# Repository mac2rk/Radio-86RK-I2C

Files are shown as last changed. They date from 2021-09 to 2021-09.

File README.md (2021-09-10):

# I2C interface for i8080 (and simlilar) computers

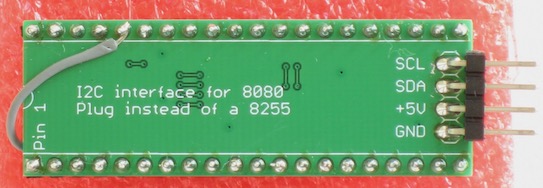
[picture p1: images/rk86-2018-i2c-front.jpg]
Board top


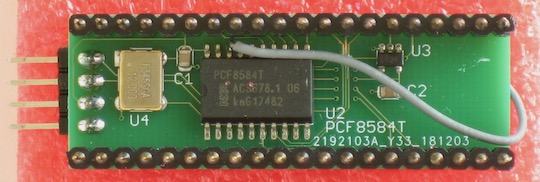
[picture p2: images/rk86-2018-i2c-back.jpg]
Board bottom


(The wire fixes an error in an intial version of the board; in the Eagle and Gerber files available here the error has been fixed.)

## Introduction

This project is an I2C interface for i8080/i8085/Z80-based computers. The interface is bulit around NXP's PCF8584 I2C bus controller. The PCB is size- and pin-compatible with the i8255 Programmable Peripheral Interface and can be plugged into i8255's socket (of course it requires different code to setup and run). A code example is provided.

## Schematic

[Schematic](Eagle/Radio86RK-I2C-schematic.pdf)

The schematic follows the datasheet for the PCF8584. 

## PCB layout 

[PCB layout](Eagle/Radio86RK-I2C-pcb.pdf)

Note that all parts, with the possible exception of the 4-pin I2C header, are on the underside of the PCB.

## Bill of Materials

U1 (8255) in the schematic is just the DIL male socket, not the actual IC.

Depending on PCF8584 programming, the following oscillator (U4) frequencies can be used: 3, 4.43, 6, 8, 12MHz. With a different board, the clock can of course be shared with the CPU or other preriperals.

Name  | Part               | Value   | Package | Quantity
----- | ------------------ | ------- | ------- | --------
U2    | I2C-bus controller | PCF8584T | S020   | 1
U3    | Signle NAND gate | 741G00DBV | SOT23-5 | 1
U4    | Oscillator         | 12MHz   | 5x7mm   | 1
C1,C2 | Capacitor          | 0.1uF   | 0805    | 2
I2C   | 0.1" pin header    |         | 1x4     | 1

## Example code

Intel 8080 assembler - can be compiled with e.g. [asm8080](https://github.com/mac2rk/asm8080). The code assumes that the PCF8584 I/O ports are mapped to memory addresses 0A000h (data port) and 0A001h (control port). 

    ; PCF8584 use example
    ; 
    ; Define PCF8584 ports
    PCF_BASE    EQU     0A000h
    DATA_REG    EQU     0
    CTRL_REG    EQU     1
    PCF_DATA    EQU     PCF_BASE+DATA_REG
    PCF_CTRL    EQU     PCF_BASE+CTRL_REG
    ;
    ; Define PCF8584 status bit masks
    PCF_BBN     EQU     01h             ; bus busy, active low
    PCF_PIN     EQU     80h             ; pending interrupt, active low
    PCF_LRB     EQU     08h             ; last received bit (typically the ACK bit)
    ;
    ; Define slave address
    SLAVE_ADDR  EQU     8
    ; Byte to send to the slave
    DATA_BYTE   EQU     'A'
    ;
                ORG     0
    ; initialize PCF8584
    PCF_INIT:
    ; program own slave address (this is required even if the address is not used)
                MVI     A, 80h          ; serial interface off; next byte will be loaded into register own address register
                STA     PCF_CTRL
                MVI     A, 55h          ; effective own address becomes 0AAh (55h<<1)
                STA     PCF_DATA
    ; program clock and I2C bus speed
                MVI     A, 0A0h         ; next byte will be loaded into the clock control register S2
                STA     PCF_CTRL
                MVI     A, 1Ch          ; system clock is 12 MHz; SCL = 90 kHz
                STA     PCF_DATA
    ; enable serial interface
                MVI     A, 0C1h         ; enable serial interface, set I2C-bus into idle mode
                STA     PCF_CTRL
    ;
    ; now send something to a slave
    PCF_MASTER_TX:
    ; wait for bus availability
                LDA     PCF_CTRL        ; load status byte
                ANI     PCF_BBN         ; is bus available?
                JZ      PCF_MASTER_TX   ; JIF not available
    ; form the slave address with the R/W bit (R=1, W=0) at LSB
                XRA     A               ; Carry = 0
                MVI     A, SLAVE_ADDR   ; load slave address
                RAL                     ; shift address left, set R/W bit to 0 (write)
                STA     PCF_DATA
    ; generate START condition on the I2C bus and clock out the address byte
                MVI     A, 0C5h          
                STA     PCF_CTRL        ; transmit address + R/W bit
    TX10:
    ; wait for the transmission to finish
                LDA     PCF_CTRL        ; load status byte
                MOV     B, A            ; store status byte to check for acknowledgement later
                ANI     PCF_PIN         ; is transmission complete?
                JNZ     TX10            ; keep polling if not complete
                MOV     A, B
    ; check if the slave acknowledged the address
                ANI     PCF_LRB         ; slave acknowledged?
                JNZ     TXSTOP          ; JIF not acknowledged; maybe the slave is busy or not present at that address
    ; slave acknowledged the address, so send the data
                MVI     A, DATA_BYTE    ; byte to be transferred
                STA     PCF_DATA        ; send the data byte to the slave
    TX20:
    ; wait for the transmission to finish
                LDA     PCF_CTRL        ; load status byte
                ANI     PCF_PIN         ; is transmission complete?
                JNZ     TX20            ; keep polling if not complete
    ; here one can check for acknowledgement and send the next byte, etc.
    TXSTOP:
    ; generate STOP condition on the I2C bus
                MVI     A, 0C3h          
                STA     PCF_CTRL        ; generate STOP condition
    ;
                JMP     PCF_MASTER_TX   ; repeat sending sequence

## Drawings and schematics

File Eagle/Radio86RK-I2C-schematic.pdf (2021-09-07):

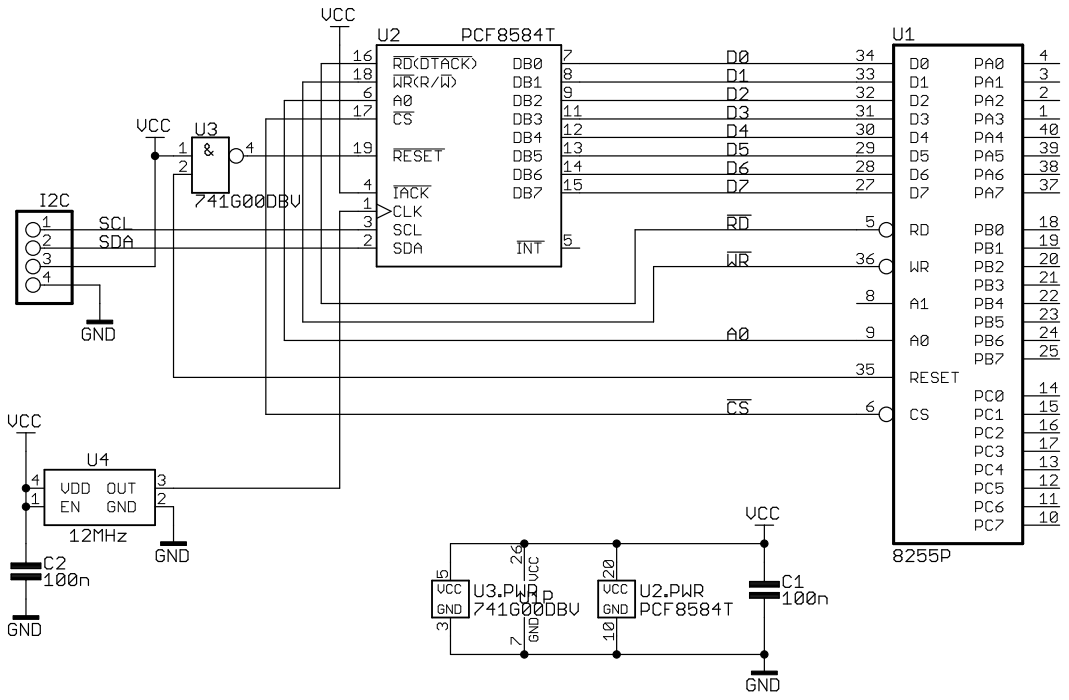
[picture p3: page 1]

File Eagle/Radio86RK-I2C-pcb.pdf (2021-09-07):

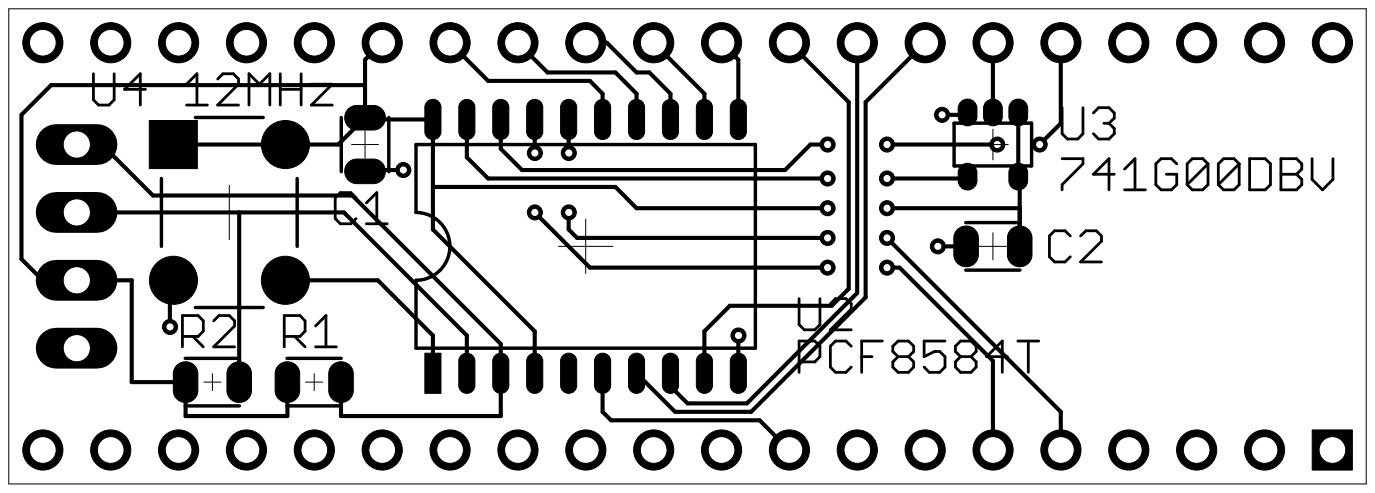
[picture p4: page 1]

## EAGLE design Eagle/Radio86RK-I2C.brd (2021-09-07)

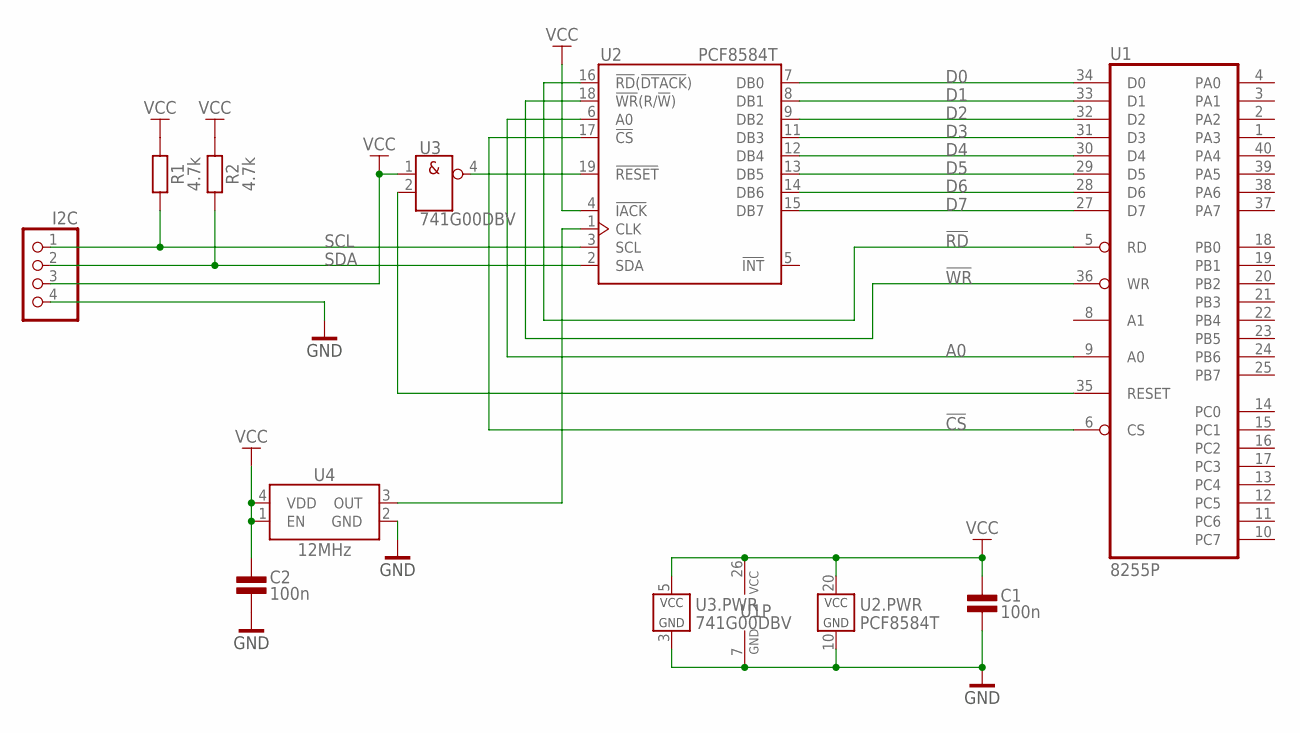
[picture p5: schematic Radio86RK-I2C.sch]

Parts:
C1, C2: 100n; 0805@1
I2C: PINHD-1X4; 1X04
R1, R2: 4.7k; 0805
U1: 8255P; DIP40W
U2: PCF8584T; SO20W
U3: 741G00DBV; SOT23-5
U4: 12MHz; XT_5X7

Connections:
!CS: U1.6 (CS), U2.17 (!CS)
!RD: U1.5 (RD), U2.16 (!RD!(!DTACK!))
!WR: U1.36 (WR), U2.18 (!WR!(R/!W!))
A0: U1.9 (A0), U2.6 (A0)
D0: U1.34 (D0), U2.7 (DB0)
D1: U1.33 (D1), U2.8 (DB1)
D2: U1.32 (D2), U2.9 (DB2)
D3: U1.31 (D3), U2.11 (DB3)
D4: U1.30 (D4), U2.12 (DB4)
D5: U1.29 (D5), U2.13 (DB5)
D6: U1.28 (D6), U2.14 (DB6)
D7: U1.27 (D7), U2.15 (DB7)
GND: C1.1, C2.1, I2C.4, U1.7 (GND), U2.10 (GND), U3.3 (GND), U4.2 (GND)
unnamed: U2.19 (!RESET), U3.4 (Y)
unnamed: U2.1 (CLK), U4.3 (OUT)
unnamed: U1.35 (RESET), U3.2 (B)
SCL: I2C.1, R1.1, U2.3 (SCL)
SDA: I2C.2, R2.1, U2.2 (SDA)
VCC: C1.2, C2.2, I2C.3, R1.2, R2.2, U1.26 (VCC), U2.4 (!IACK), U2.20 (VCC), U3.1 (A), U3.5 (VCC), U4.1 (EN), U4.4 (VDD)

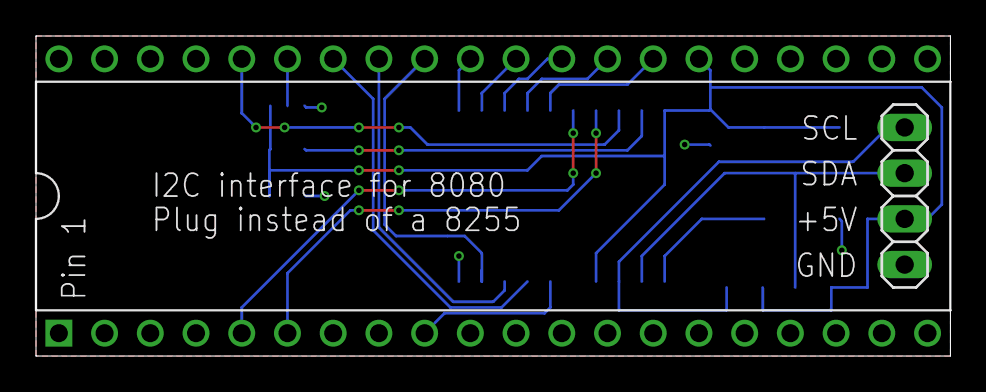
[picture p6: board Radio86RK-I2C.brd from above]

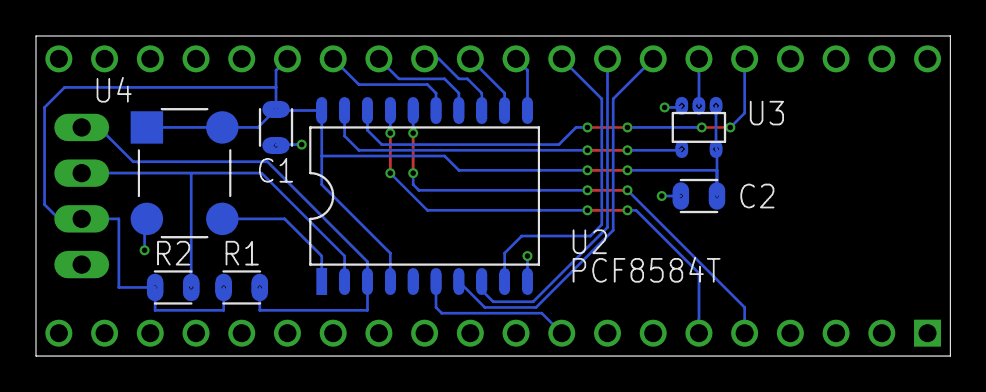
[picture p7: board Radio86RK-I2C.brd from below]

Board: 2 copper layers, 50.8 x 17.8 mm, 9 parts (7 on the bottom side), 19 nets.
